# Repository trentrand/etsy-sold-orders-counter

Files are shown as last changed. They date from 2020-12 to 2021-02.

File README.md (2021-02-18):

# etsy orders counter

A desktop screen that displays a live counter of your Etsy store orders!

__Powered by FreeRTOS on a ESP-8266 microcontroller__

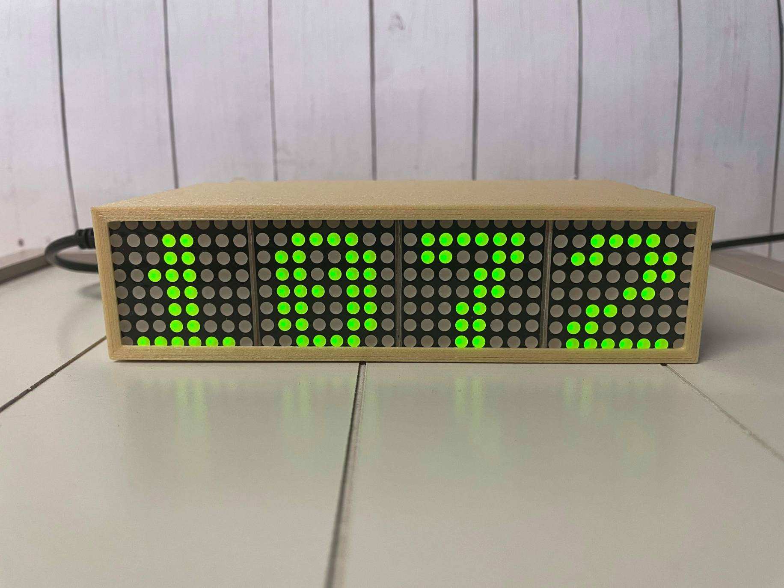
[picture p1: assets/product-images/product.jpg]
Product image


> See more images in the [assets directory](./assets/product-images)

## Build

This project extends the
[esp-open-rtos makefile](https://github.com/SuperHouse/esp-open-rtos/blob/master/common.mk).

### Setup

You should follow standard instructions in the
[esp-open-rtos README](https://github.com/SuperHouse/esp-open-rtos/blob/master/README.md)
to ensure your environment has the dependencies necessary to build the project.

Next you must setup your secrets in the `./config.h` file. See instructions in
`./config.example.h` to get started.

Once you've setup your secrets, you can flash your board with this project's
firmware by executing the following commands in your terminal:

```
$ make rebuild
$ make flash
```

Depending on your operating system and connected peripherals, you may need
to change the `SERIAL_PORT` variable in `./Makefile`. To find the path of
your connected microcontroller, try looking at the results of `ls /dev`.

### Supported build environments

This project is developed within a virtualized instance of Ubuntu.

The Makefile also includes a utility target `dev` which will step your
shell into a containerized image which has the necessary dependency for
esp-open-rtos. On MacOSX, because of limitations with Docker, you can not
mount usb devices to a docker container. This means that utility targets
like `flash` and `erase_flash` must be invoked outside of the container.

## Debugging

You can view the serial output of your microcontroller by using whichever
program you'd like, just set the baud rate to 115200. This project is setup
to use `picocom`, just invoke the `monitor` target with `make monitor`.

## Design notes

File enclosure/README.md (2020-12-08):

# Project Enclosure Dimensions

The numbers here record measurements of the various parts used in this project.

Together these create requirements for the modeled enclosure.

## Enclosure Front Face:

LED Display Dimensions:
  - Width 131.25 mm
  - Height 32 mm
  - Depth 13 mm

## Enclosure Body

Estimated Required Depth 32 mm

## Enclosure Backplate

Outer Dimensions: 96.6 mm x 44.5 mm

Screw Bracket Dimensions:
  - Width 92.95mm (90.75 mm + (2 * 1.1mm M2 screw hole radius))
  - Height 39.45 mm (37.25 mm + (2 * 1.1mm M2 screw hole radius))
  - Metric M2 threaded hole (~2.2 mm) 
  - Screws offset 0.75 mm X and Y on smaller long-edge

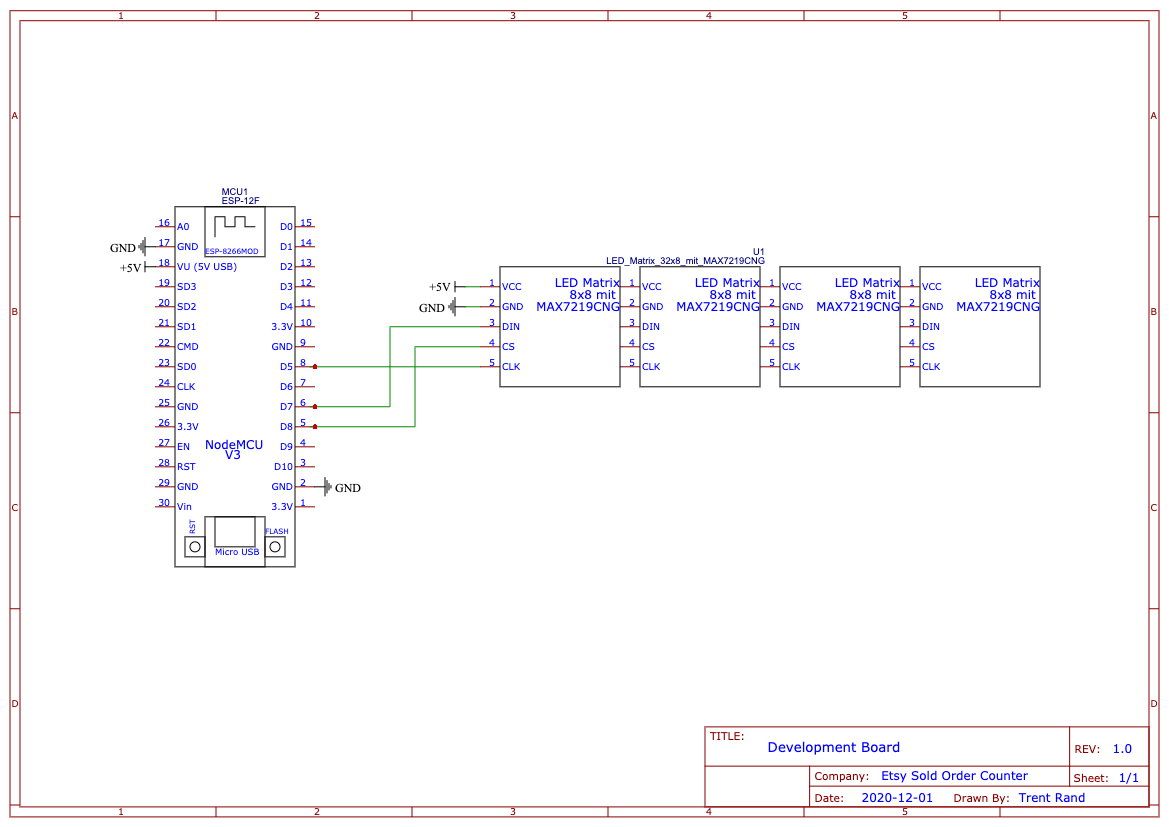
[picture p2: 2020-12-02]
Schematic.png

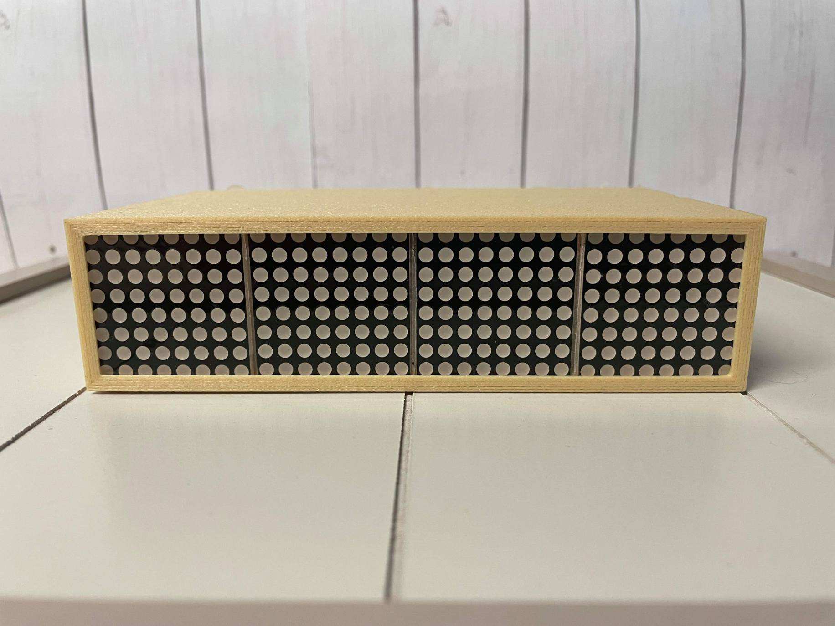
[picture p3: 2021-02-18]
assets/product-images/enclosure_front.jpg

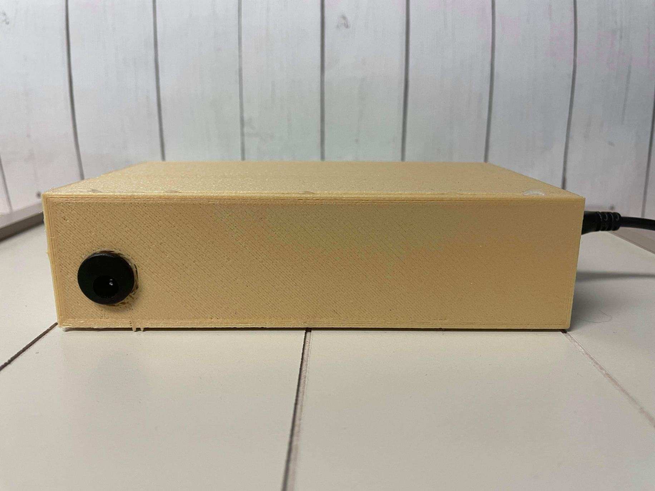
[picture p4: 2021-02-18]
assets/product-images/enclosure_back.jpg

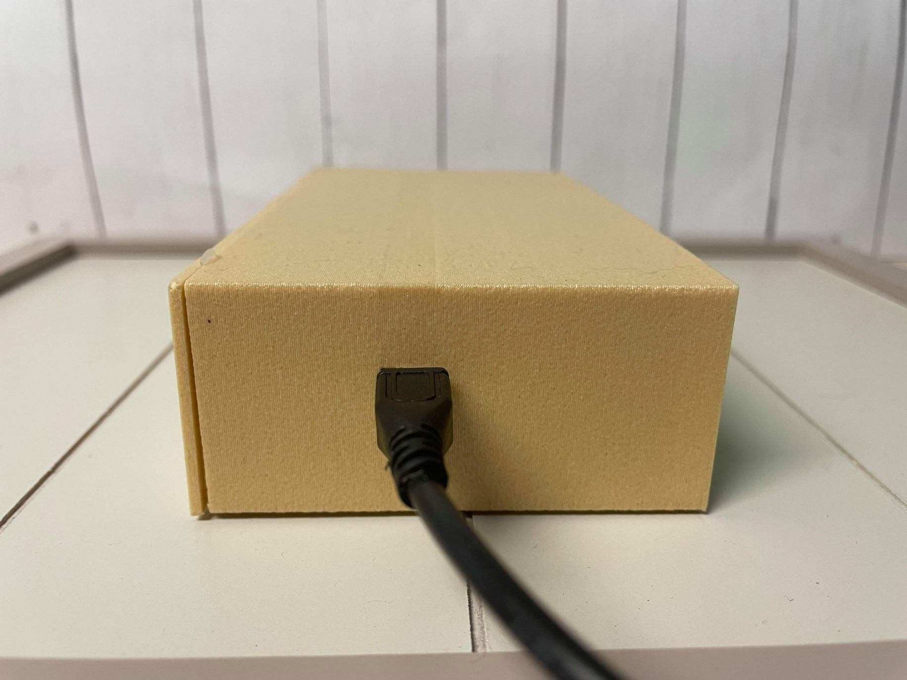
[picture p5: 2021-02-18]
assets/product-images/enclosure_side_left_powered.jpg

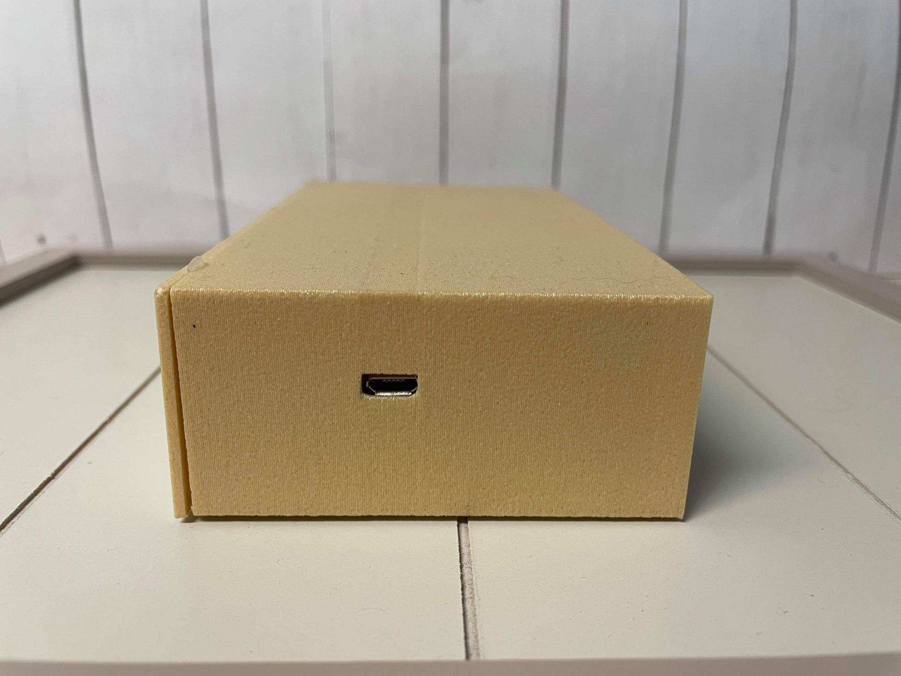
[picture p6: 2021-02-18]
assets/product-images/enclosure_side_left.jpg

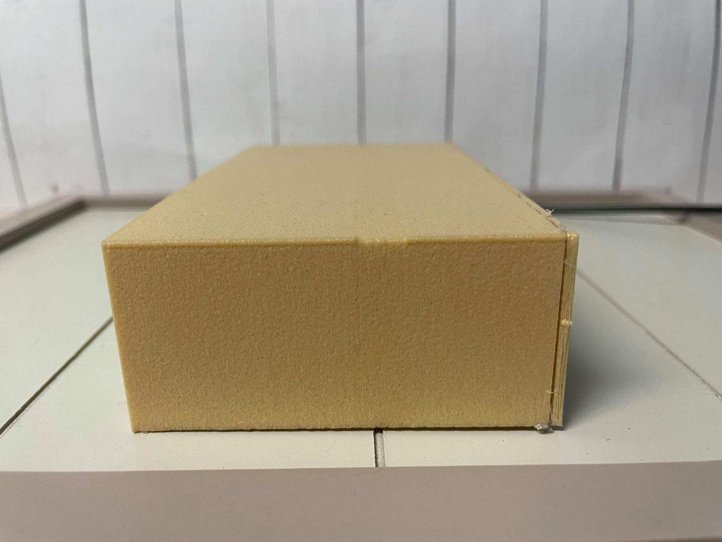
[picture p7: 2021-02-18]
assets/product-images/enclosure_side_right.jpg

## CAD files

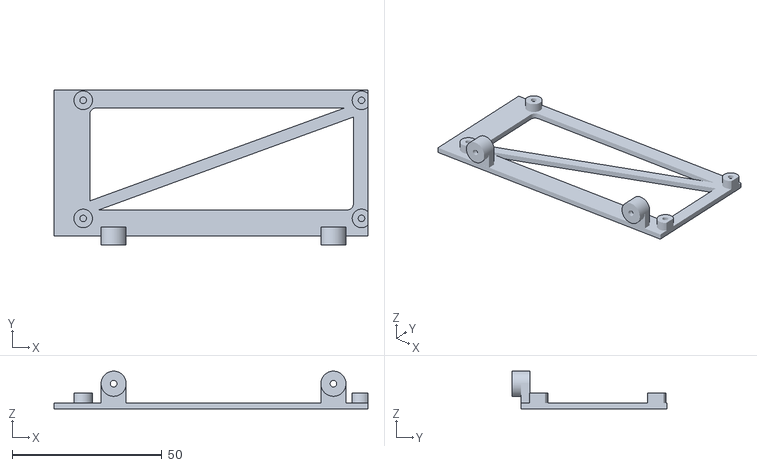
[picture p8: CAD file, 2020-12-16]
enclosure/Rack.stl
104.9 x 51.7 x 12.6

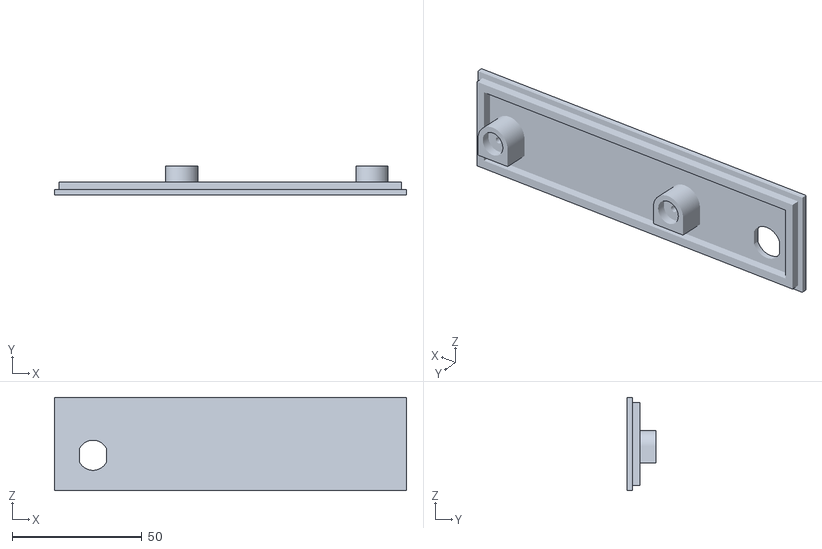
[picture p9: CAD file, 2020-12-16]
enclosure/Backplate.stl
135.8 x 11.0 x 36.0

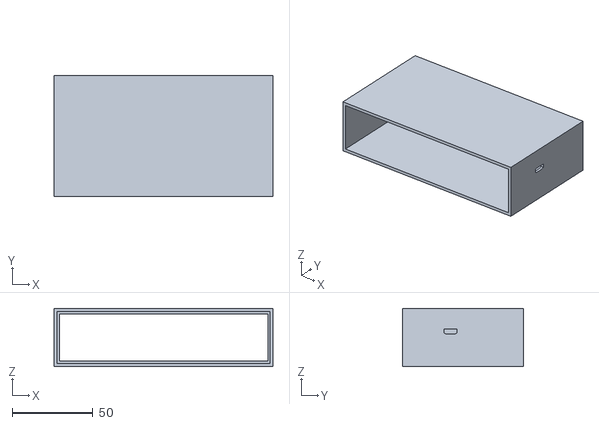
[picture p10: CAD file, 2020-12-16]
enclosure/Body.stl
135.8 x 74.7 x 36.0

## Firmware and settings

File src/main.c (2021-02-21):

#include "espressif/esp_common.h"
#include "esp/uart.h"
#include "FreeRTOS.h"
#include "task.h"
#include <string.h>
#include <wifi_config.h>

#include "./https_fetch.c"
#include "./controllers/max7219_display.c"

/* #include "gdbstub.h" */

int orderCount = 0;

void on_wifi_ready() {
}

void user_init(void) {
  uart_set_baud(0, 115200);
  printf("SDK version:%s\n", sdk_system_get_sdk_version());

  /* gdbstub_init(); */

  display_init();
  xTaskCreate(&fetch_order_count_task, "Task: Fetch order count", 2048, NULL, 2, NULL);
  xTaskCreate(&display_render_task, "Task: Render order count", 2048, NULL, 3, NULL);
}

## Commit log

2020-11-21 Add example task to poll HTTP Get request for etsy orders
    I attempted to create a polling task which requests etsy order count
    from a specified shop. Eventually this number will be displayed on an
    LED matrix; but for now I need to debug and understand why the request
    fails.
    [main.c]
2020-11-21 Add gdb debugging support using resetnow/esp-gdbstub
    The package resetnow/esp-gdbstub is used to add gdb debugging
    capabilities to this project. By using the `make debug` target,
    application runtime can be captured on exceptions and do backtraces,
    read and write memory, and set software and hardware breakpoints
    and watchpoints.
    Esp-open-rtos code runs in flash memory, which on the ESP-12F supports a
    maximum of 1 hardware breakpoints and 1 hardware watchpoint.
    Because only 1 hardware breakpoint is supported in flash memory, using a
    hardware breakpoint (via `thb`) is a good approach. Alternatively you may
    use as many breakpoints in application code as you'd like by invoking
    `gdbstub_do_break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
    [main.c]
2020-11-24 Rewrite HTTP GET polling task to use mbedtls library
    The http_get task has been rewritten to use mbedtls instead of BearSSL.
    I'm seeing better luck with this library's success rate, although it
    still fails on x508 certificate verification intermittently.
    [main.c]
2020-11-29 Temporarily update `lib/esp-open-rtos` dependency to use forked version
    I extended the `esp-open-rtos/extras/MAX7219` software driver and pushed
    my changes upstream for merge into the main repository. Until the change
    is merged, this project will use my fork of the dependency.
    See [SuperHouse/esp-open-rtos PR #765](https://github.com/SuperHouse/esp-open-rtos/pull/765)
    for the proposed upstream changes.
    The forked esp-open-rtos dependency adds software driver support for
    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
2020-11-29 Add example application code to render 8x8 displays using MAX7219 driver
    The `lib/esp-open-rtos` dependency has been updated to include my
    changes for support to draw 8x8 bitmaps with a MAX7219 driver.
    With the updated software driver, these changes create an example
    implementation by rendering a revolving 0-9 number sequence across four
    cascaded 8x8 LED matrix displays.
    Later changes will tie this example code in with the HTTP fetch task in
    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
2020-11-29 Attempt to match SSL hostname to Common Name in x509 server certificate
    The HTTPS request to Etsy's API intermittently returns 400 responses for
    the first few network requests after the board is booted. It's unclear
    what causes this, but one common suggestion through troubleshooting
    forums is to ensure the common name from the certificate matches the
    hostname during the initial connection.
2020-11-30 Use Jsmn library to parse order count from Etsy API response
    These changes add minimal validation and parsing of the Etsy API
    response using the 'Jsmn' JSON parser/tokenizer library.
    The order count is currently printed and returned to the HTTPS fetch
    task, but is discarded from there. Subsequent changes will share this
    value with the display render task.
2020-12-01 Clean up gdb debugger initialization, breakpoints and xtensa logging
    Esp-gdbstub has been cleaned up and is no longer initialized in the
    application. The initialization code was left inline so that it's
    easy enough to uncomment when working on a feature.
    In the future we can clean this up by wrapping the Makefile inclusions
    and C application code in a 'debug' environment variable.
    Xtensa debugging has been disabled. It might be worthwhile to explore
    what debug levels 1-3 look like, since they might print worthwhile
    information for general debugging. Again, this would be nice to
    conditionally set when we're inside a "debug" build.
    [main.c]
2020-12-02 Add schematic for development board circuit
    This schematic shows a minimal circuit necessary for running the
    firmware on an ESP-12F development board with four cascaded MAX7219
    drivers for 8x8 LED Matrix displays.
    Later changes will add the power supply circuit for the alternate 5V
    DC Barrel connector.
2020-12-06 Add example directory of the Sounds SD card
    An example directory has been added to assets which demonstrates the
    directory structure and file naming convention necessary to replicate
    when setting up the DFPlayer module's SD card.
    Users should copy the contents of `example-sd-card-image/` onto the root
    of their SD card.
    *Note*: The firmware does not currently support this module.
2020-12-07 Add exported STL for enclosure back cap
    This exported STL models the back cap of the enclosure and features four
    M2 metric bolt mounting points for the circuit board.
    This model was designed to fit a 2x1 segment of a snappable 2x2 PCB
    prototype board. See the README in this directory for exact dimensions.
    This part will likely require a built-in fastener since it's the final
    piece that must be inserted and fastened when assembling the gadget.
    [BackCap.stl]
2020-12-08 Add exported STL for enclosure faceplate and body
    This exported STL models the front face and body of the enclosure as a
    single printable piece.
    This design is missing built-in fasteners for both the backplate and
    display. These will come in a secondary design once this is printed and
    tested for fit.
    [Backplate.stl, Body.stl]
2020-12-16 Update enclosure faceplate and body to reduce bezel to 1 millimeter
    The previous enclosure mounted the screen and circuit board parallel to
    one another, which meant that the wide width of the circuit board would
    restrict the display from having a minimally sized bezel. Because the
    board will now be mounted on a rack which floats perpendicular to the
    screen, the enclosure can be much shorter and narrower at the expense of
    added depth.
    display. These will come in an updated design once this is printed
    and tested for fit.
    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
    [Body.stl]
2020-12-16 Update enclosure backplate and add mounted circuit board tray
    This exported STL models the back cap of the enclosure and features two
    M2 metric bolt mounting points for the circuit board tray.
    Because the board will now be mounted on a rack which floats
    perpendicular to the screen, the enclosure can be much shorter and
    narrower (and thus with reduced bezel) at the expense of added depth.
    prototype board. See the README in this directory for exact board
    dimensions.
    It is unclear whether the tray aligns the micro-controller's micro usb
    port with the slot in the case. To be tested during assembly.
    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
    [Backplate.stl, Rack.stl]
2021-02-18 Add images of the hardware product
    These changes present the final hardware product with images of
    powered-on and off states from each directional angle.
    Later changes will present images of the assembled circuit board,
    circuit tray mount and peripheral wiring.
2021-02-21 Add user-friendly initial install Wifi configuration
    These changes add the
    [HomeACcessoryKid/esp-wifi-config](https://github.com/HomeACcessoryKid/esp-wifi-config)
    library, which allows users to easily configure the device's wifi
    connection without hard-coding their credentials and flashing the
    microcontroller.
    Network credentials are stored, and when they are missing, invalid or
    if the network doesn't exist, the device will host a Wifi access point.
    Users can connect to this access point, visit the local address and
    choose and authenticate with their network.
    [main.c]
